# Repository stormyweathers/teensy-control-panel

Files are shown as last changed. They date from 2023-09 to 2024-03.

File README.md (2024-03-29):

# Teensy Control Panel

This project consists of a PCB and arduino library that together provide various I/O capabilities for the teensy 4.0

## PCB Features
    * All jst connectors are in the XH series, except the stemma-QT connectors, which are JST-PH
    * 2x RJ45 ports, each with 4-channel GPIO capability
    * 1x JST 5-pin connector for rotary encoder
    * 8x JST 3-pin connectors for potentiometer analog inputs
    * 3x JST 2-pin connectors for switches or buttons
    * 1x JST 2-pin connector to expose the programming pin if necessary
    * 2x Stemma-QT connectors for I2C comms
        * One of these is intended to be used for an OLED screen 

## Control code features

I've only used this project for myself so far, so the documentation is sparse.
If you're interested, please reach out and I'll use that as motivation to write more clearly.

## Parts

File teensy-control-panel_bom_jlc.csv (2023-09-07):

Comment | Designator | Footprint | LCSC Part #
220n | C201,C301,C401,C501,C601,C701,C801,C901 | C_0603_1608Metric | C21120
I2C_1 | J101 | JST_SH_SM04B-SRSS-TB_1x04-1MP_P1.00mm_Horizontal | C160404
I2C_0 | J102 | JST_SH_SM04B-SRSS-TB_1x04-1MP_P1.00mm_Horizontal | C160404
1k | R201,R301,R401,R501,R601,R701,R801,R901 | R_0603_1608Metric | C21190
10k | RV201,RV301,RV401,RV501,RV601,RV701,RV801,RV901 | JST_PH_B3B-PH-SM4-TB_1x03-1MP_P2.00mm_Vertical | C265082
RotaryEncoder_Switch | SW101 | JST_PH_B5B-PH-SM4-TB_1x05-1MP_P2.00mm_Vertical | C265086
SW_0 | SW102,SW103,SW104 | JST_PH_B2B-PH-SM4-TB_1x02-1MP_P2.00mm_Vertical | C265003
PRGM | SW105 | JST_PH_B2B-PH-SM4-TB_1x02-1MP_P2.00mm_Vertical | C265003

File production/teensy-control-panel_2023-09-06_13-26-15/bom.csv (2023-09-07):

Designator | Footprint | Quantity | Value | LCSC Part #
U101 | Teensy40 | 1 | Teensy4.0

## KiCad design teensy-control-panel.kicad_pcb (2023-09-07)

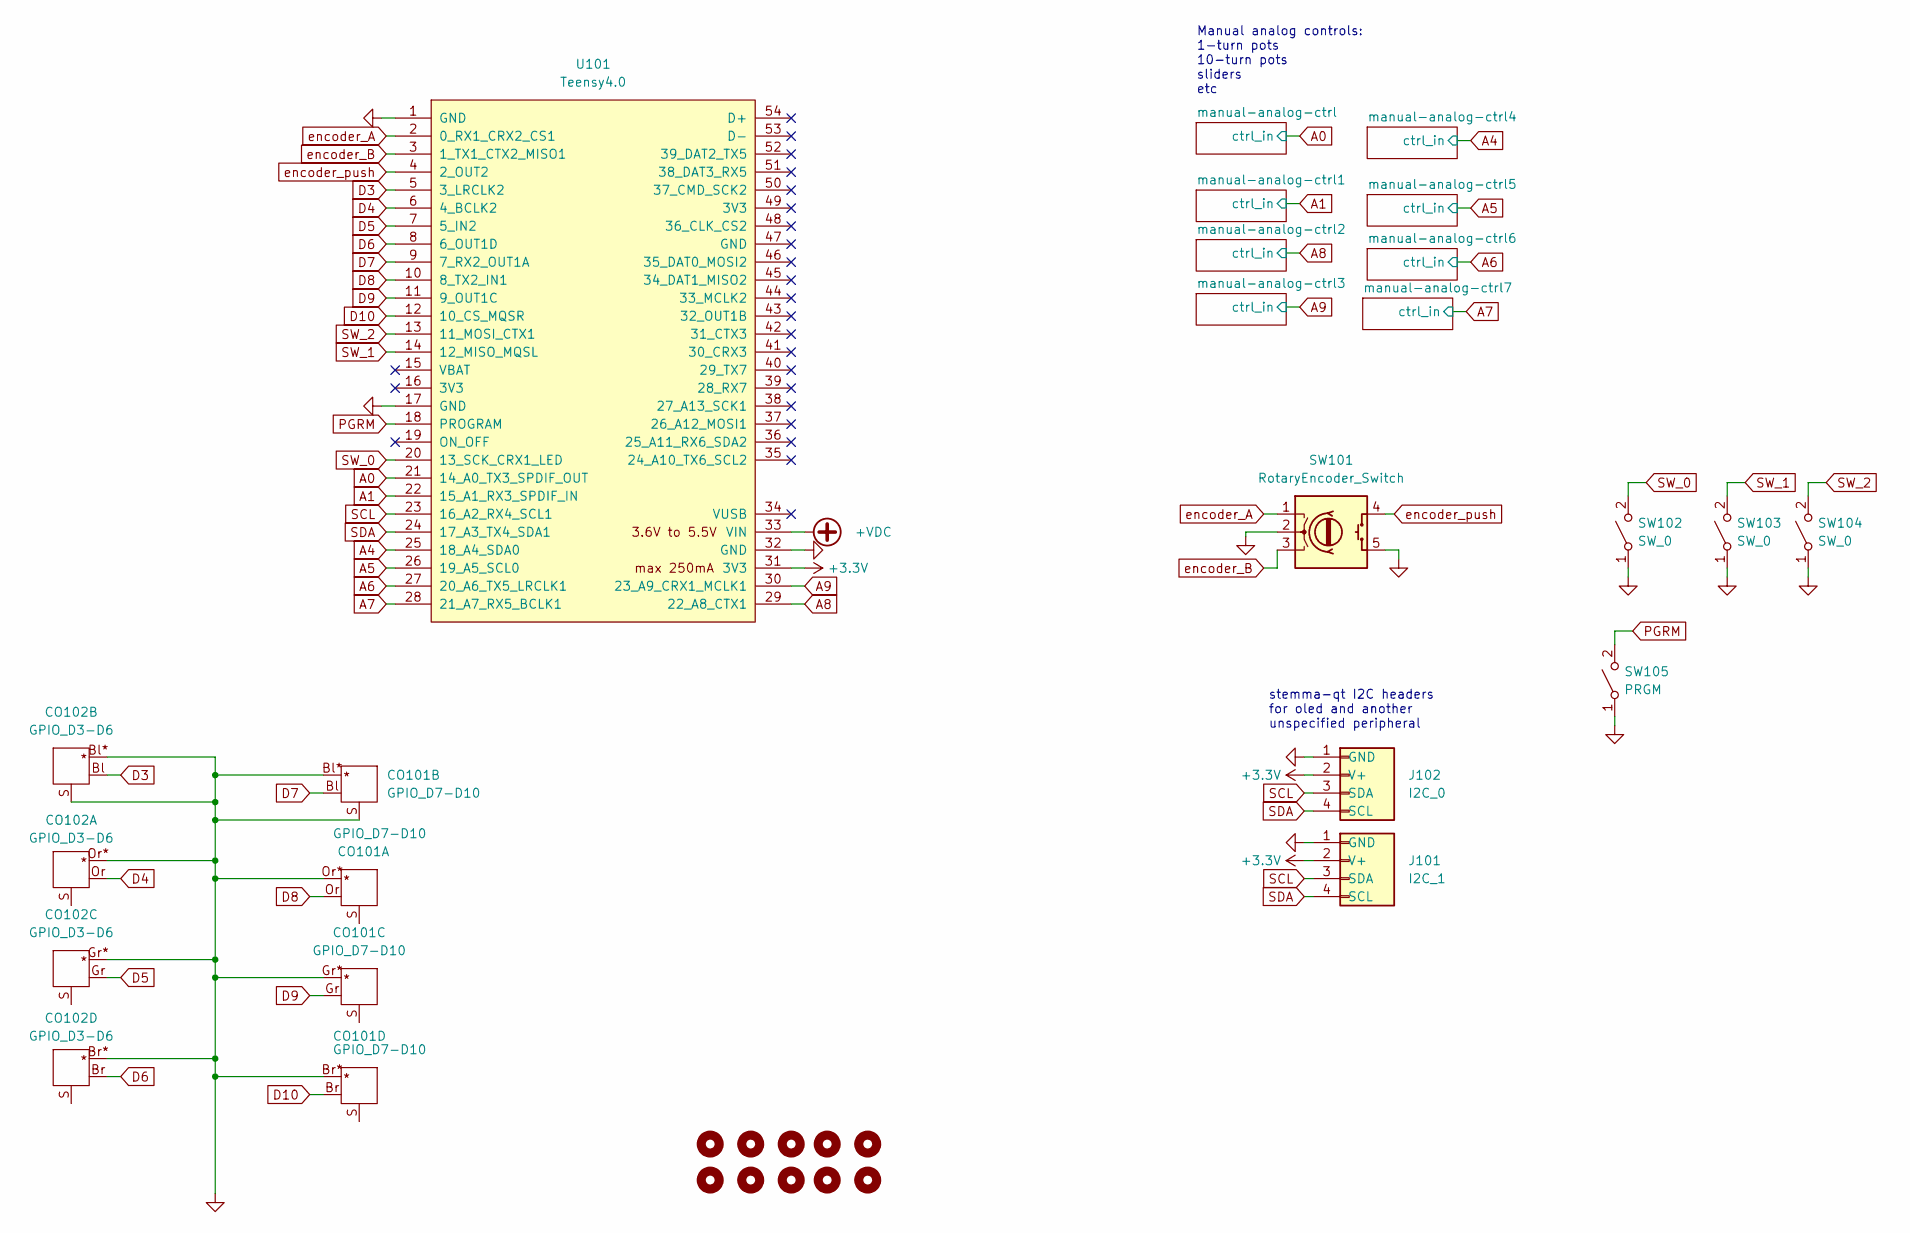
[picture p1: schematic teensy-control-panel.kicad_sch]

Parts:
CO101: GPIO_D7-D10; RJ45
CO102: GPIO_D3-D6; RJ45
H101, H102, H103, H104, H105, H106, H107, H108, H109, H110: MountingHole; MountingHole_3.2mm_M3
J101: I2C_1; JST_SH_SM04B-SRSS-TB_1x04-1MP_P1.00mm_Horizontal; jlcpcb C160404
J102: I2C_0; JST_SH_SM04B-SRSS-TB_1x04-1MP_P1.00mm_Horizontal; jlcpcb C160404
SW101: RotaryEncoder_Switch; JST_PH_B5B-PH-SM4-TB_1x05-1MP_P2.00mm_Vertical; jlcpcb C265086
SW102, SW103, SW104: SW_0; JST_PH_B2B-PH-SM4-TB_1x02-1MP_P2.00mm_Vertical; jlcpcb C265003
SW105: PRGM; JST_PH_B2B-PH-SM4-TB_1x02-1MP_P2.00mm_Vertical; jlcpcb C265003
U101: Teensy4.0; Teensy40_reduced

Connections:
+3.3V: J101.2 (V+), J102.2 (V+), U101.31 (3V3); also elsewhere on the board
+VDC: U101.33 (VIN)
A0: U101.21 (14_A0_TX3_SPDIF_OUT); also elsewhere on the board
A1: U101.22 (15_A1_RX3_SPDIF_IN); also elsewhere on the board
A4: U101.25 (18_A4_SDA0); also elsewhere on the board
A5: U101.26 (19_A5_SCL0); also elsewhere on the board
A6: U101.27 (20_A6_TX5_LRCLK1); also elsewhere on the board
A7: U101.28 (21_A7_RX5_BCLK1); also elsewhere on the board
A8: U101.29 (22_A8_CTX1); also elsewhere on the board
A9: U101.30 (23_A9_CRX1_MCLK1); also elsewhere on the board
D3: CO102.Bl, U101.5 (3_LRCLK2)
D4: CO102.Or, U101.6 (4_BCLK2)
D5: CO102.Gr, U101.7 (5_IN2)
D6: CO102.Br, U101.8 (6_OUT1D)
D7: CO101.Bl, U101.9 (7_RX2_OUT1A)
D8: CO101.Or, U101.10 (8_TX2_IN1)
D9: CO101.Gr, U101.11 (9_OUT1C)
D10: CO101.Br, U101.12 (10_CS_MQSR)
GND: CO101.Bl*, CO101.Br*, CO101.Gr*, CO101.Or*, CO101.S, CO102.Bl*, CO102.Br*, CO102.Gr*, CO102.Or*, CO102.S, J101.1 (GND), J102.1 (GND), SW101.2 (C), SW101.5 (S2), SW102.1 (A), SW103.1 (A), SW104.1 (A), SW105.1 (A), U101.1 (GND), U101.17 (GND), U101.32 (GND); also elsewhere on the board
PGRM: SW105.2 (B), U101.18 (PROGRAM)
SCL: J101.3 (SDA), J102.3 (SDA), U101.23 (16_A2_RX4_SCL1)
SDA: J101.4 (SCL), J102.4 (SCL), U101.24 (17_A3_TX4_SDA1)
SW_0: SW102.2 (B), U101.20 (13_SCK_CRX1_LED)
SW_1: SW103.2 (B), U101.14 (12_MISO_MQSL)
SW_2: SW104.2 (B), U101.13 (11_MOSI_CTX1)
encoder_A: SW101.1 (A), U101.2 (0_RX1_CRX2_CS1)
encoder_B: SW101.3 (B), U101.3 (1_TX1_CTX2_MISO1)
encoder_push: SW101.4 (S1), U101.4 (2_OUT2)

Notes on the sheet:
stemma-qt I2C headers for oled and another unspecified peripheral
Manual analog controls: 1-turn pots 10-turn pots sliders etc

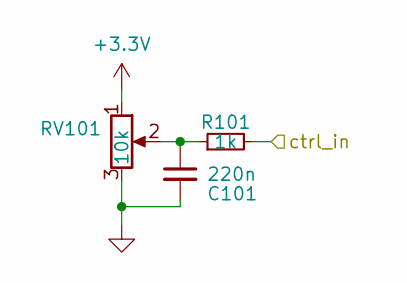
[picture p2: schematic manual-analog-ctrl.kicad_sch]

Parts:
C101: 220n; C_0603_1608Metric; jlcpcb C21120
R101: 1k; R_0603_1608Metric; jlcpcb C21190
RV101: 10k; JST_PH_B3B-PH-SM4-TB_1x03-1MP_P2.00mm_Vertical; jlcpcb C265082

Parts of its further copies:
C201, C301, C401, C501, C601, C701, C801, C901: 220n; C_0603_1608Metric; jlcpcb C21120
R201, R301, R401, R501, R601, R701, R801, R901: 1k; R_0603_1608Metric; jlcpcb C21190
RV201, RV301, RV401, RV501, RV601, RV701, RV801, RV901: 10k; JST_PH_B3B-PH-SM4-TB_1x03-1MP_P2.00mm_Vertical; jlcpcb C265082

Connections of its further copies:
+3.3V: RV201.1, RV301.1, RV401.1, RV501.1, RV601.1, RV701.1, RV801.1, RV901.1; also elsewhere on the board
A0: R201.2; also elsewhere on the board
A1: R301.2; also elsewhere on the board
A4: R601.2; also elsewhere on the board
A5: R701.2; also elsewhere on the board
A6: R901.2; also elsewhere on the board
A7: R801.2; also elsewhere on the board
A8: R401.2; also elsewhere on the board
A9: R501.2; also elsewhere on the board
GND: C201.2, C301.2, C401.2, C501.2, C601.2, C701.2, C801.2, C901.2, RV201.3, RV301.3, RV401.3, RV501.3, RV601.3, RV701.3, RV801.3, RV901.3; also elsewhere on the board
unnamed: C201.1, R201.1, RV201.2
unnamed: C301.1, R301.1, RV301.2
unnamed: C401.1, R401.1, RV401.2
unnamed: C501.1, R501.1, RV501.2
unnamed: C601.1, R601.1, RV601.2
unnamed: C701.1, R701.1, RV701.2
unnamed: C801.1, R801.1, RV801.2
unnamed: C901.1, R901.1, RV901.2

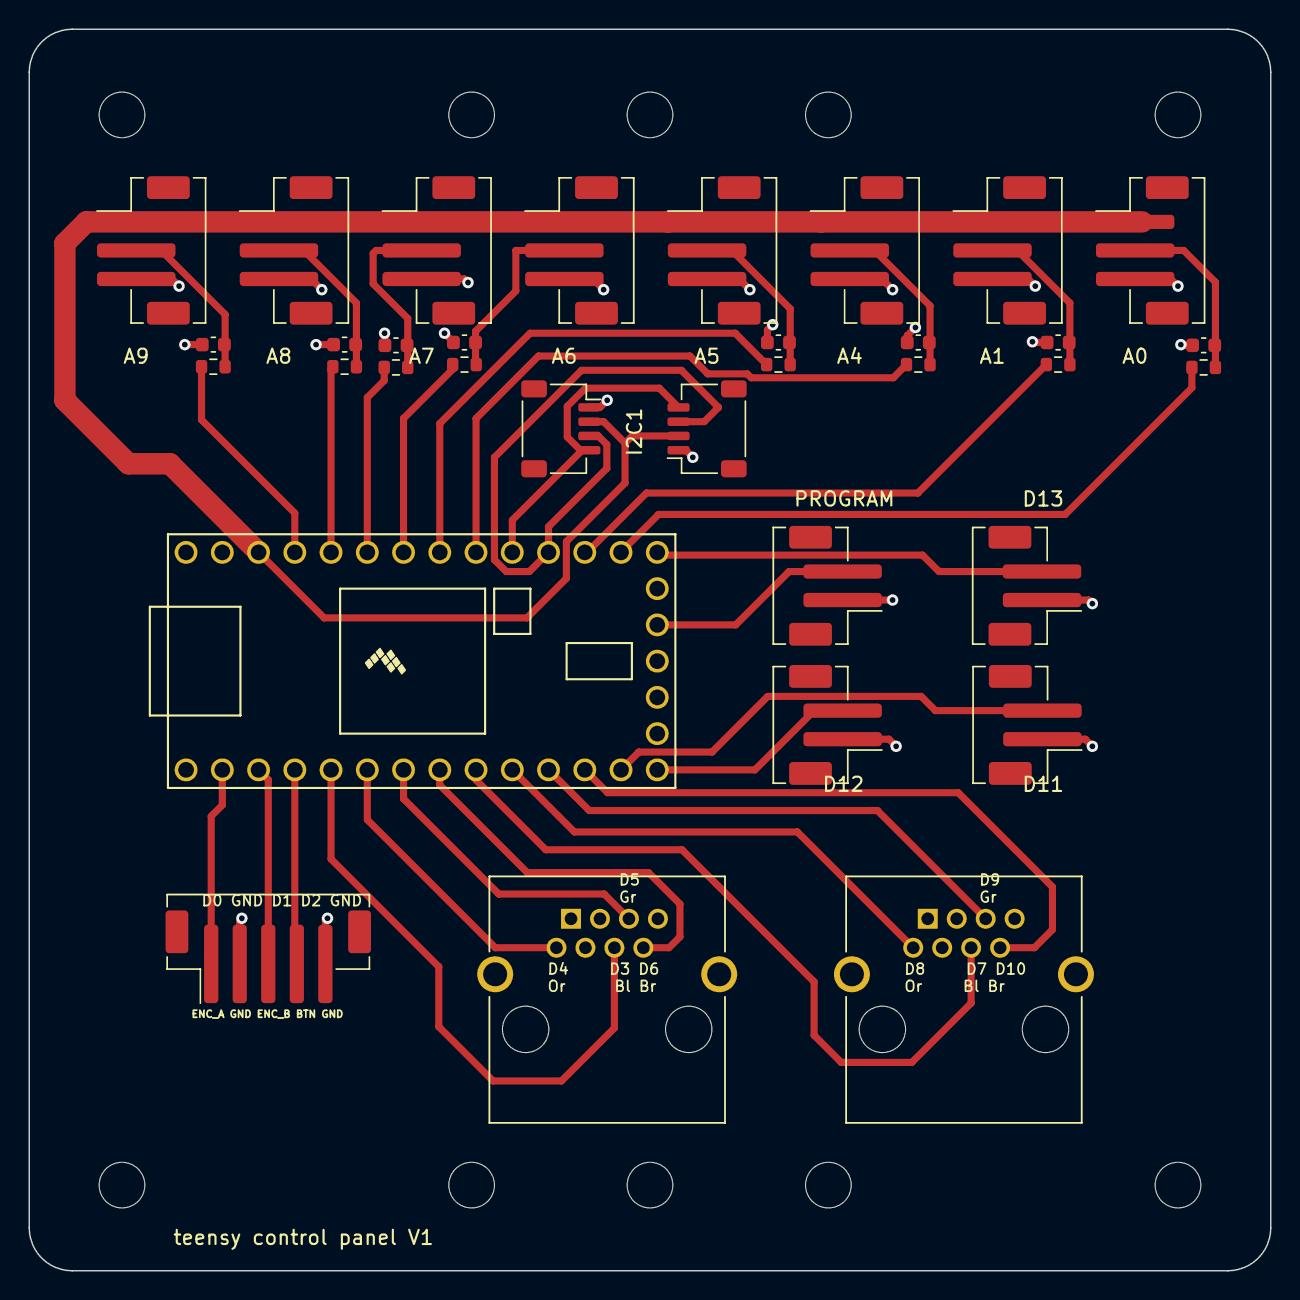
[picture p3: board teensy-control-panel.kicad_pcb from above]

Board: 2 copper layers, 87.0 x 87.0 mm, 44 parts (0 on the bottom side), 35 nets.

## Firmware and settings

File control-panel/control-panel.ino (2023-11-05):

#include "control-panel.h"
#include "TeensyTimerTool.h"

controlPanel panel;
TeensyTimerTool::PeriodicTimer read_timer(TeensyTimerTool::TCK);

void timer_callback(){
  panel.readState();
}

void setup() {
  // put your setup code here, to run once:
  Serial.begin(9600);
  
  panel.init();
  // For some reason, only 8,10,12 work as expected.  All other vals default to 12 bits
  panel.resolution=8;
  delay(250); // wait for the OLED to power up
  
  
  Serial.println("init done");

  read_timer.begin(timer_callback,1000);
}

void loop() {
  // put your main code here, to run repeatedly:
    //panel.readState();                         //call as often as possible, around every ms or so
    //panel.reportDiff();
    if (panel.anyInputsChanged){
      panel.reportStateOled(true);
    }
    delay(10);
    //panel.enc.tick();
    //if (panel.enc.valueChanged()){
    //    Serial.print("Encoder new value: ");
    //    Serial.println(panel.enc.getValue());
    //}
}

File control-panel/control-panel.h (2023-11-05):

#ifndef CONTROL_PANEL_H
#define CONTROL_PANEL_H
#include <SPI.h>
#include <Wire.h>
#include <Adafruit_GFX.h>
#include <Adafruit_SH110X.h>
#include "EncoderTool.h"
#include <digitalWriteFast.h>
#include <Bounce2.h>

using namespace EncoderTool;

// Pin definitions
namespace controlPanelBoard{
  //encoder pins
  constexpr uint8_t enc_pinA = 0, enc_pinB = 1, enc_pinBtn = 2;

  // button/switch inputs
  constexpr uint8_t joystick_button=11, button=12, toggle=13;
  constexpr uint8_t digital_in[] = {joystick_button,button,toggle};

  //Analog slider/pot inputs
  constexpr uint8_t joystick_x = A0, joystick_y = A1, joystick_z = A4;
  constexpr uint8_t slider_r = A5, slider_c = A6, slider_l = A7;
  // unused ports on the board: A8,A9
  constexpr uint8_t analog_in[] = {joystick_x,joystick_y,joystick_z,slider_r,slider_c,slider_l}; 

  //Pins for oled screen
  constexpr uint16_t screen_width=128, screen_height=128;
  constexpr int8_t oled_reset=-1;

  //Pins for digital outputs
  constexpr uint8_t digital_out_0[] = {3,4,5,6};
  constexpr uint8_t digital_out_1[] = {7,8,9,10}; 
  //constexpr uint8_t digital_out_all[] = {3,4,5,6,7,8,9,10};
  //using 22,23 as digital outs instead of analog outs
  constexpr uint8_t digital_out_all[] = {3,4,5,6,7,8,9,10,22,23};
  constexpr uint8_t num_digital_outs = 8;
}

class controlPanel {
  public:

    int resolution;

    //Constructor
    controlPanel();

    // Initializer
    void init();

    //Read all inputs
    void readState();

    // serial print the difference between current and previous state
    void reportDiff();

    // write the state of all inputs to OLED
    void reportStateOled(bool update_display);

    //
    void poll();

    //debounce objects for digital inputs
    Bounce2::Button joystick_button = Bounce2::Button();
    Bounce2::Button button = Bounce2::Button();
    Bounce toggle = Bounce();

    //flags to detect changed inputs
    bool anyInputsChanged;
    bool encoderChanged;
    bool encoderButtonChanged;
    bool digitalInChanged;
    bool analogInChanged;

    PolledEncoder enc;
    Adafruit_SH1107 display = Adafruit_SH1107(controlPanelBoard::screen_width, controlPanelBoard::screen_height, &Wire1, controlPanelBoard::oled_reset, 1000000, 100000);

    //Report the input states
    bool digital_in_state[3];
    uint16_t analog_in_state[8];
    bool digital_out_state[8];

    // neutral values, may change over long time
    int joystick_x0;
    int joystick_y0;
    int joystick_z0;

    // Converted to floats
    float joystick_x;
    float joystick_y;
    float joystick_z;

    //write to the digital outputs
    bool dWrite(uint8_t,bool);

    //Retreive pin number from digital output ports
    uint8_t getPinNumber(uint8_t);

  private:
    //Previous state for noticing changes
    bool digital_in_state_cache[3];
    uint16_t analog_in_state_cache[8];
    bool digital_out_state_cache[8];
};

//Constructor
controlPanel::controlPanel(){

  // Initialize digital outputs and set to zero ASAP
  // Dont want to have anything turned on by mistake at startup
  for (uint8_t idx=0; idx< sizeof(controlPanelBoard::digital_out_all)/sizeof(controlPanelBoard::digital_out_all[0]); idx++){
    pinModeFast(controlPanelBoard::digital_out_all[idx], OUTPUT);
    digitalWriteFast(controlPanelBoard::digital_out_all[idx], 0);
  }
}

void controlPanel::init(){

  enc.begin(controlPanelBoard::enc_pinA, controlPanelBoard::enc_pinB, controlPanelBoard::enc_pinBtn);  
  display.begin(0x3D, true);
  delay(250); // wait for the OLED to power up
  // Clear the buffer.
  display.clearDisplay();
  display.setTextSize(1);             // Normal 1:1 pixel scale
  display.setTextColor(SH110X_WHITE);        // Draw white text
  display.setCursor(0,0);             // Start at top-left corner
  display.println("Teensy Control Panel Booting up!");
  display.display();

  // Initialize debounce objects for digital inputs
  button.attach(controlPanelBoard::button,INPUT_PULLUP);
  button.interval(25);
  button.setPressedState(LOW);

  joystick_button.attach(controlPanelBoard::joystick_button,INPUT_PULLUP);
  joystick_button.interval(25);
  joystick_button.setPressedState(LOW);

  toggle.attach(controlPanelBoard::toggle,INPUT_PULLUP);
  toggle.interval(25);

  analogReadResolution(this->resolution);
  //Set default values at halfway point
  this->joystick_x0 = pow(2,this->resolution-1)-1;
  this->joystick_y0 = pow(2,this->resolution-1)-1;
  this->joystick_z0 = pow(2,this->resolution-1)-1;
}

void controlPanel::poll(){
  //Poll all digital input pins
  
  //Encoder
  enc.tick();
  encoderChanged = enc.valueChanged();
  encoderButtonChanged = enc.buttonChanged();

  joystick_button.update();
  button.update();
  toggle.update();
  digitalInChanged = joystick_button.changed() | button.changed() | toggle.changed();

}

void controlPanel::readState(){
  //Read states of all inputs, cache old state, and compare to detect changes
  poll();

  analogInChanged = 0;
  //analog_inputs
  analogInChanged = 0;
  for (uint8_t idx=0; idx<sizeof(controlPanelBoard::analog_in)/sizeof(controlPanelBoard::analog_in[0]);idx++ ){
    analog_in_state_cache[idx] = analog_in_state[idx];
    analog_in_state[idx] = analogRead(controlPanelBoard::analog_in[idx]);
    //single bit changes are common due to fluctuations, set a diff threshold
    analogInChanged |= (  0 < abs( static_cast <int16_t> (analog_in_state[idx]) - static_cast<int16_t>(analog_in_state_cache[idx])   )    );
  }

  anyInputsChanged = encoderChanged | encoderButtonChanged | analogInChanged | digitalInChanged;

  this->joystick_x = (this->analog_in_state[0]-this->joystick_x0)/pow(2,this->resolution-1);
  this->joystick_y = (this->analog_in_state[1]-this->joystick_y0)/pow(2,this->resolution-1);
  this->joystick_z = (this->analog_in_state[2]-this->joystick_z0)/pow(2,this->resolution-1);
}


void controlPanel::reportDiff(){
    if (encoderChanged)             // do we have a new encoder value?
    {
        Serial.print("Encoder new value: ");
        Serial.println(enc.getValue());
    }
    if (encoderButtonChanged)            // do we have a new button state?
    {
        Serial.print("Encoder button state: ");
        Serial.println(enc.getButton() == LOW ? "pressed" : "released");
    }

    if (analogInChanged ){
      Serial.print("Analog input vals: ");
      for (uint8_t idx=0; idx<sizeof(analog_in_state)/sizeof(analog_in_state[0]);idx++ ){
        Serial.print("  ");
        Serial.print(analog_in_state[idx]);
        Serial.print("  ");
      }
      Serial.println("");
    }

    if (digitalInChanged){
      Serial.print("Digital input vals: ");
      for (uint8_t idx=0; idx<sizeof(digital_in_state)/sizeof(digital_in_state[0]);idx++ ){
        Serial.print("  ");
        Serial.print(digital_in_state[idx]);
        Serial.print("  ");
      }
      Serial.println();
    }
}
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

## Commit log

2023-09-07 init commit, V1 ready for fab
    [bom.csv, designators.csv, manual-analog-ctrl.kicad_sch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]
2023-09-25 fixed namespace conflict - digitalWrite
    [control-panel.h, control-panel.ino]
2023-10-02 used debounce library for digital inputs, use OLED for reporting output, use timers for reading inputs
2023-11-05 arduino drier: added joystick float vals with tunable zero point, pins 22/23 (A8/A9) routed to digital IO
2024-03-29 changed case of naming
